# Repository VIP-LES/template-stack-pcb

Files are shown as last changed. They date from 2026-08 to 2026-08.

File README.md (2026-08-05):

# LEOS Stack PCB Template

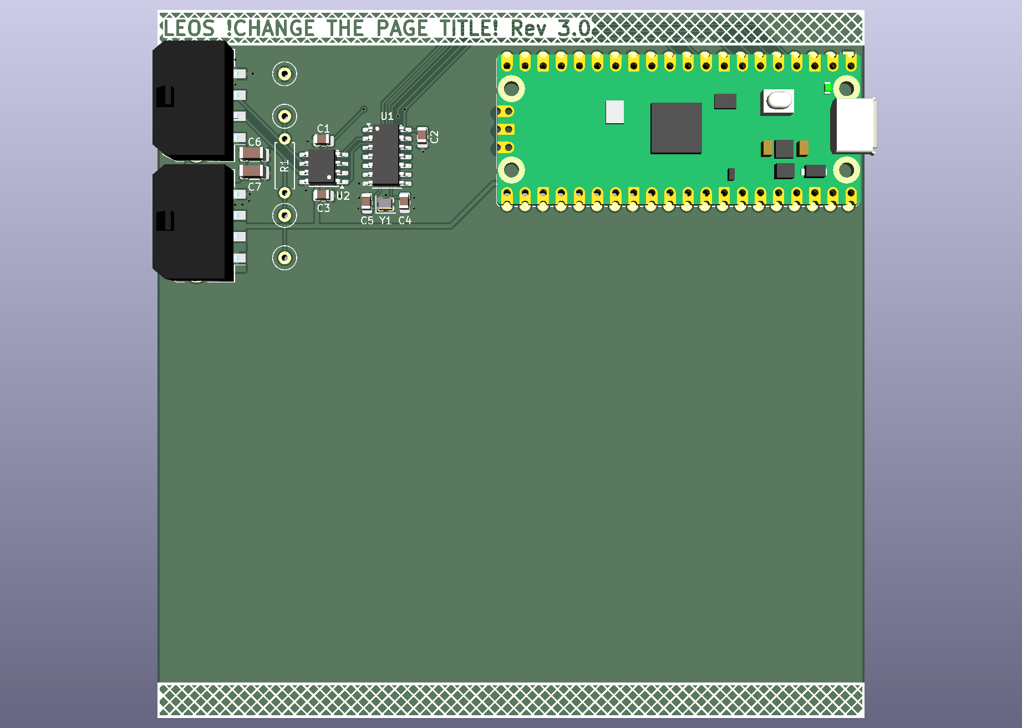
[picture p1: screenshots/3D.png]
3D render of the LEOS Stack PCB template


This repository is the starting-point PCB template for VIP Lightning From the Edge of Space (LEOS). **All LEOS modules should be spun off from this template** so that every module begins with the standard Raspberry Pi Pico, CAN-FD network, stack connectors, board shape, and mechanical layout.

## Create a module repository from this template

Do not fork or clone this repository as the permanent home of a new module. Create a fresh repository from the public GitHub template instead:

1. Open this template repository on GitHub.
2. Select **Use this template**, then **Create a new repository**.
3. Choose the LEOS organization as the owner and enter the new module's repository name and description.
4. Leave **Include all branches** unchecked unless the module specifically needs work from non-default template branches.
5. Choose public visibility, then select **Create repository**.
6. Clone the newly created repository and open `LEOS-stack-template.kicad_pro` in KiCad.

GitHub also allows this template to be selected from the **Repository template** menu while creating a new repository. See GitHub's [repository template instructions](https://docs.github.com/en/repositories/creating-and-managing-repositories/creating-a-repository-from-a-template) for the current interface.

## Before designing

- Rename the root KiCad project, schematic, and PCB files for the module.
- Change the root sheet/page title in both the schematic and PCB. Rename or add schematic sheets so their names clearly describe each circuit domain.
- Update the **date** and **revision** in both the schematic and PCB Page Settings. These fields are used in the PCB silkscreen, so stale metadata will be manufactured onto the board.
- Replace the template title and delete the instructional text box on the root schematic once it is no longer needed.
- Use separate schematic sheets to isolate circuit domains, and document the design well enough for the schematic to explain itself.

## Design expectations

- Use [pinout.xyz](https://pinout.xyz/) with the Pico 2 view when selecting configurable pins. Avoid using SPI0 for other devices because it is reserved for the high-throughput CAN bus; SPI1, I2C0, and UART0 are exposed as starting interfaces.
- Keep the standard CAN-FD and stack-connector circuitry intact unless a reviewed module requirement calls for a change.
- Verify that every schematic symbol, PCB footprint, and selected BOM item agree. Record the manufacturer, manufacturer part number (MPN), and DigiKey information for each part.
- Prefer practical, hand-placeable packages such as SOIC, 0805, 1206, SOT, and TSSOP. Do not choose extremely small packages when a larger suitable option exists.
- Commit coherent, incremental changes with descriptive messages. Do not commit generated outputs, junk files, or Gerbers when they can be regenerated from the KiCad sources.
- Review the schematic, layout, footprints, sourcing, and manufacturer recommendations before ordering hardware.

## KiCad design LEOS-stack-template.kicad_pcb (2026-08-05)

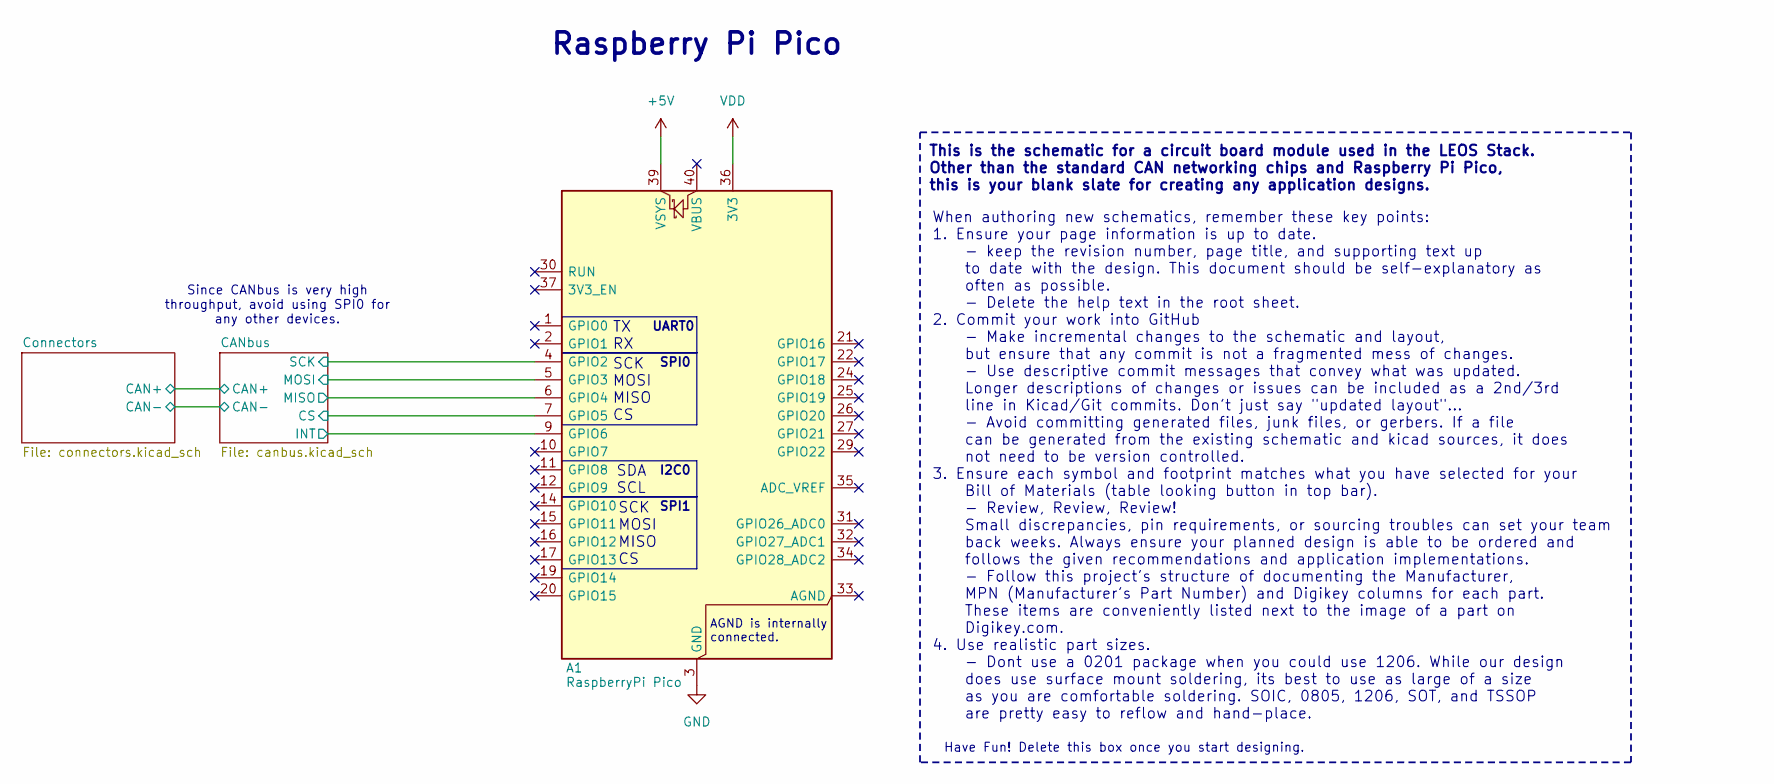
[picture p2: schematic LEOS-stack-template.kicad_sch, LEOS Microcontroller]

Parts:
A1: RaspberryPi Pico; RaspberryPi_Pico_Common_Unspecified; MPN PIM724; Digikey 1778-PIM724-ND

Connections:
+5V: A1.39 (VSYS); also elsewhere on the board
/CANbus/CS: A1.7 (GPIO5); also elsewhere on the board
/CANbus/INT: A1.9 (GPIO6); also elsewhere on the board
/CANbus/MISO: A1.6 (GPIO4); also elsewhere on the board
/CANbus/MOSI: A1.5 (GPIO3); also elsewhere on the board
/CANbus/SCK: A1.4 (GPIO2); also elsewhere on the board
GND: A1.3 (GND), A1.8 (GND), A1.13 (GND), A1.18 (GND), A1.23 (GND), A1.28 (GND), A1.38 (GND); also elsewhere on the board
VDD: A1.36 (3V3); also elsewhere on the board

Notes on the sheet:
This is the schematic for a circuit board module used in the LEOS Stack. Other than the standard CAN networking chips and Raspberry Pi Pico, this is your blank slate for creating any application designs.
SPI1
Raspberry Pi Pico
SCK MOSI MISO CS
Have Fun! Delete this box once you start designing.
Since CANbus is very high throughput, avoid using SPI0 for any other devices.
SPI0
SDA SCL
TX RX
When authoring new schematics, remember these key points: 1. Ensure your page information is up to date. - keep the revision number, page title, and supporting text up to date with the design. This document should be self-explanatory as often as possible. - Delete the help text in the root sheet. 2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
UART0
I2C0
AGND is internally connected.

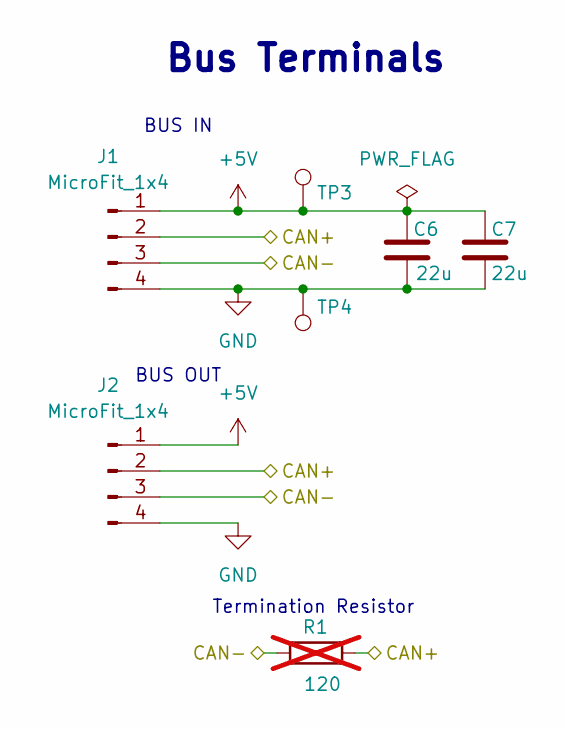
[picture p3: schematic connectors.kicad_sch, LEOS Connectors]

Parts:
C6, C7: 22u; C_1206_3216Metric; MPN CL31B226MPHNNNE; Digikey 1276-3148-1-ND
J1, J2: MicroFit_1x4; Molex_MicroFit3.0_43650-0410_1x04_Horizontal; MPN 0436500409; Digikey WM1882CT-ND
R1: 120; R_Axial_DIN0207_L6.3mm_D2.5mm_P7.62mm_Horizontal; MPN CF14JT120R; Digikey CF14JT120RCT-ND; not fitted
TP3: 5V Test Point; TestPoint_Loop_D2.60mm_Drill0.9mm_Beaded; MPN 5000; Digikey 36-5000-ND
TP4: GND Test Point; TestPoint_Loop_D2.60mm_Drill0.9mm_Beaded; MPN 5001; Digikey 36-5001-ND

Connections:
+5V: C6.1, C7.1, J1.1, J2.1, TP3.1 (1_1); also elsewhere on the board
/CANbus/CAN+: J1.2, J2.2, R1.2; also elsewhere on the board
/CANbus/CAN-: J1.3, J2.3, R1.1; also elsewhere on the board
GND: C6.2, C7.2, J1.4, J2.4, TP4.1 (1_1); also elsewhere on the board

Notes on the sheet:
BUS OUT
Bus Terminals
BUS IN
Termination Resistor

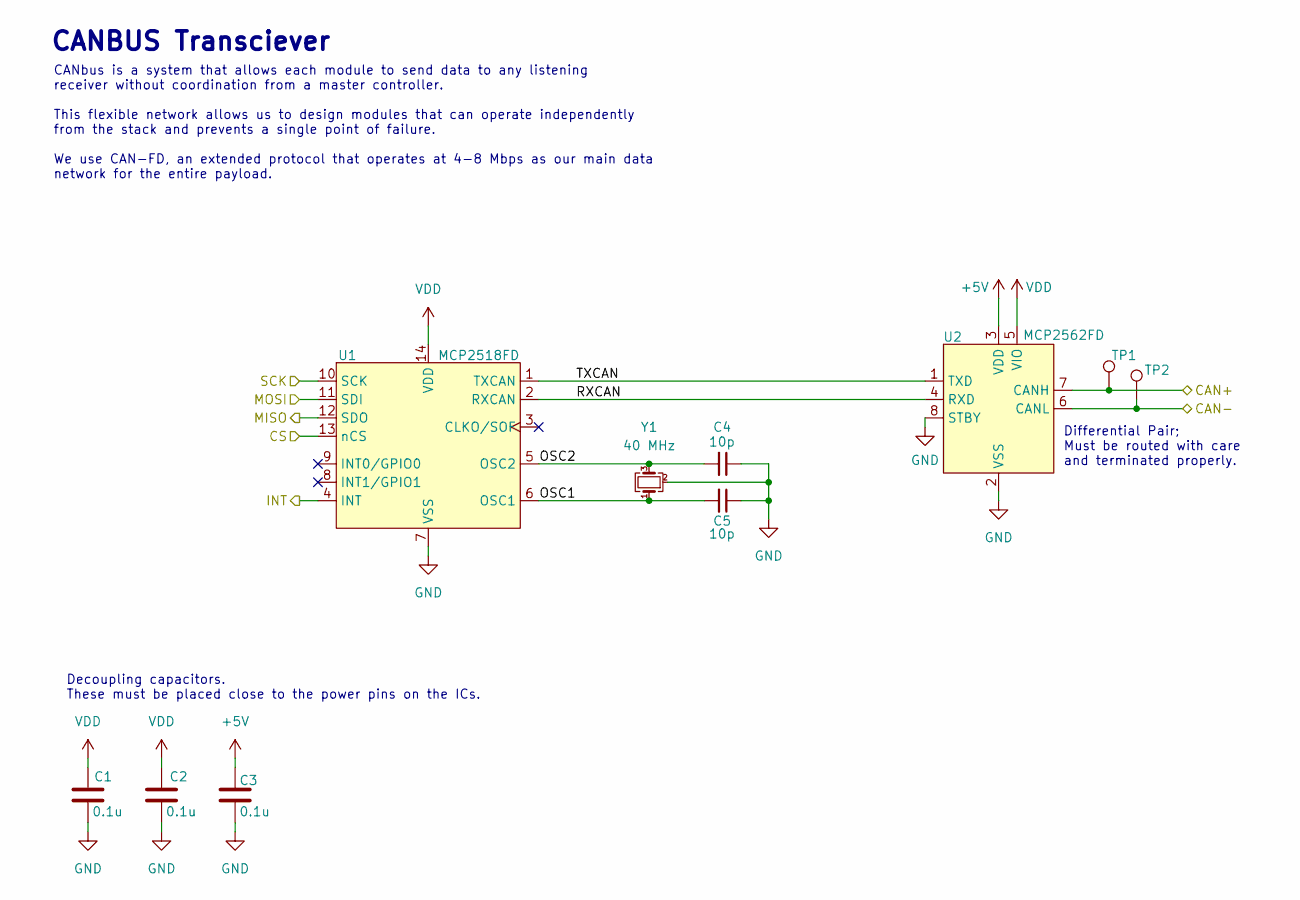
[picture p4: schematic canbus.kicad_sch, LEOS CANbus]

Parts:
C1, C2, C3: 0.1u; C_0805_2012Metric; MPN CL21B104KBCNNNC; Digikey 1276-1003-1-ND
C4, C5: 10p; C_0805_2012Metric; MPN CL21C100CBANNNC; Digikey 1276-2561-1-ND
TP1: CAN-H Test Point; TestPoint_Loop_D2.60mm_Drill0.9mm_Beaded; MPN 5004; Digikey 36-5004-ND
TP2: CAN-L Test Point; TestPoint_Loop_D2.60mm_Drill0.9mm_Beaded; MPN 5116; Digikey 36-5116-ND
U1: MCP2518FD; SOIC-14_3.9x8.7mm_P1.27mm; MPN MCP2518FDT-E/SL; LCSC C626758
U2: MCP2562FD; SOIC-8_3.9x4.9mm_P1.27mm; MPN MCP2562FDT-H/SN; LCSC C511335
Y1: 40 MHz; Crystal_SMD_2016-4Pin_2.0x1.6mm; MPN ECS-400-10-37B2-CKY-TR; Digikey 50-ECS-400-10-37B2-CKY-TRCT-ND

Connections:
+5V: C3.1, U2.3 (VDD); also elsewhere on the board
/CANbus/CAN+: TP1.1 (1_1), U2.7 (CANH); also elsewhere on the board
/CANbus/CAN-: TP2.1 (1_1), U2.6 (CANL); also elsewhere on the board
/CANbus/CS: U1.13 (nCS); also elsewhere on the board
/CANbus/INT: U1.4 (INT); also elsewhere on the board
/CANbus/MISO: U1.12 (SDO); also elsewhere on the board
/CANbus/MOSI: U1.11 (SDI); also elsewhere on the board
/CANbus/OSC1: C5.2, U1.6 (OSC1), Y1.1
/CANbus/OSC2: C4.2, U1.5 (OSC2), Y1.3
/CANbus/RXCAN: U1.2 (RXCAN), U2.4 (RXD)
/CANbus/SCK: U1.10 (SCK); also elsewhere on the board
/CANbus/TXCAN: U1.1 (TXCAN), U2.1 (TXD)
GND: C1.2, C2.2, C3.2, C4.1, C5.1, U1.7 (VSS), U2.2 (VSS), U2.8 (STBY), Y1.2 (G), Y1.4 (G); also elsewhere on the board
VDD: C1.1, C2.1, U1.14 (VDD), U2.5 (VIO); also elsewhere on the board

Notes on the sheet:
Differential Pair; Must be routed with care and terminated properly.
CANBUS Transciever
CANbus is a system that allows each module to send data to any listening receiver without coordination from a master controller. This flexible network allows us to design modules that can operate independently from the stack and prevents a single point of failure. We use CAN-FD, an extended protoco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
Decoupling capacitors. These must be placed close to the power pins on the ICs.

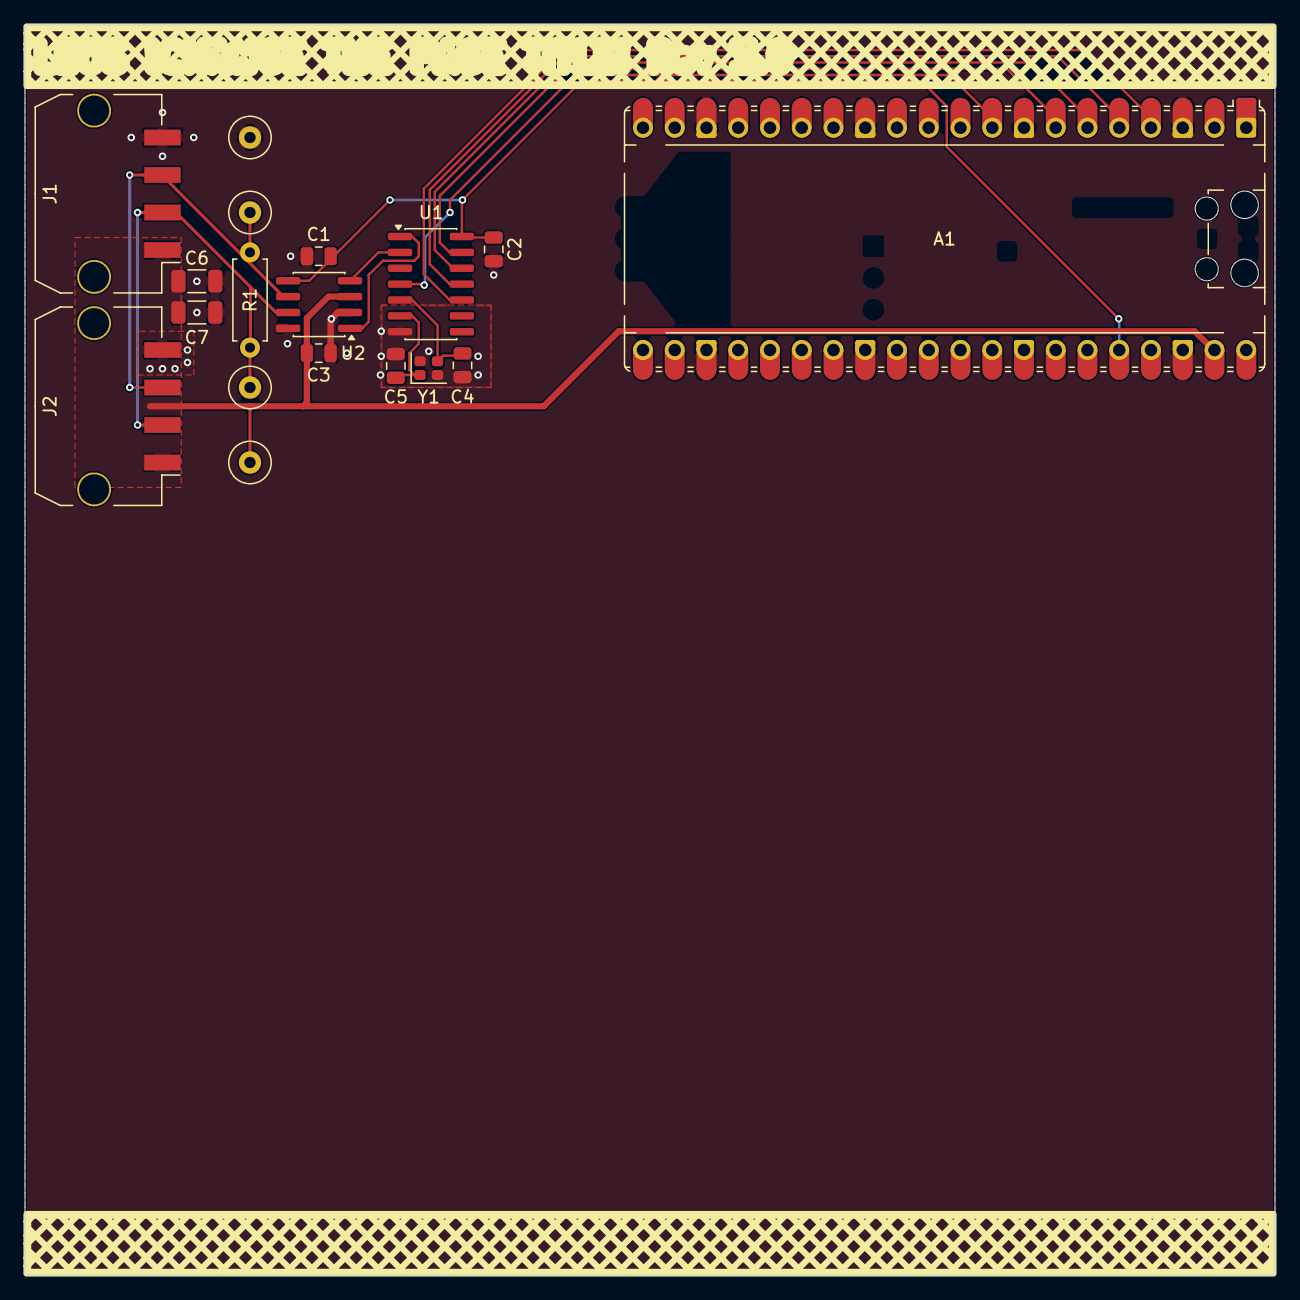
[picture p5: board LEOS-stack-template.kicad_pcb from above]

Board: 2 copper layers, 100.0 x 100.0 mm, 18 parts (0 on the bottom side), 14 nets.

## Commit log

2025-09-09 Initial R1 Template PCB Design
    [LEOS-stack-template.kicad_pcb, LEOS-stack-template.kicad_sch]
2025-09-26 Redesigned Rev 2 fixing 0603 cap size and layout
    [LEOS-stack-template.kicad_pcb, LEOS-stack-template.kicad_sch]
2025-09-26 Clean up tracks to remove warnings
    [LEOS-stack-template.kicad_pcb]
2026-02-15 New redesign featuring updated components, new sheets, better routing, and 100% 3D View
    [LEOS-stack-template.kicad_pcb, LEOS-stack-template.kicad_sch, canbus.kicad_sch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]
2026-02-16 Improved via placement, added LCSC part numbers.
    [LEOS-stack-template.kicad_pcb, LEOS-stack-template.kicad_sch, canbus.kicad_sch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]
2026-02-16 Updated routing for CANbus crystal. Should improve stencil process.
    [LEOS-stack-template.kicad_pcb]
2026-02-16 Add drill origin, removed footprint locks, and cleaned up fab notes
    [LEOS-stack-template.kicad_pcb]
2026-02-16 Update bad part num for 0.1u
    [LEOS-stack-template.kicad_sch, canbus.kicad_sch, connectors.kicad_sch]
2026-02-17 Add .gitignore for KiCad and common file types
    Add common file patterns to .gitignore for KiCad, backups, outputs, and OS junk.
2026-08-04 Add design help message and bump revision number.
    [LEOS-stack-template.kicad_sch]
2026-08-04 Update MCP symbols to remove Exposed Pad pin.
    [canbus.kicad_sch]
2026-08-05 Add design rule overrides and auto board naming
    [LEOS-stack-template.kicad_pcb]
2026-08-05 Version 3.0
    This revision includes a number of changes, notably:
    - larger 0805/1206 parts and reduced BOM
    - SMD/TH Pads for the Pico Devboard
    - Document variable Silkscreen text
    - Text documentation throughout schematics
    [LEOS-stack-template.kicad_pcb, LEOS-stack-template.kicad_sch, canbus.kicad_sch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]
2026-08-22 Ignore PCB backup files in .gitignore
